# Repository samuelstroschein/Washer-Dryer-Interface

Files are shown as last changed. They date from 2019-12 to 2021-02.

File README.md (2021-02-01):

# A washing machine/dryer status "illuminated sign"

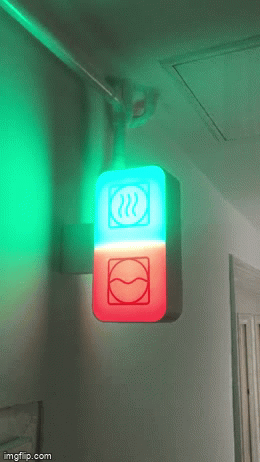
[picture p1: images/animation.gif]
animation


## Summary:

An illuminated sign that indicates whether the dryer and/or washing machine is running, finished or off. An ESP8266 processes information and sends instructions over WiFi to another ESP8266, which is built into the illuminated sign, which light(s) to turn on or off. The "sign ESP8266" controls two separate LED strips which represent either the washing machine or dryer respectively. Since all logic is happening on the client which is not build into the sign, adjusting the programmed logic when your dryer or washer is on or off is easily modifiable to suit your needs. Theoretically, you can just build the sign and display whatever you want or modify the CAD file to make the illuminated sign "wall mountable" (like a clock). 

## Technical Details

### What you need:

1. 2x ESP8266
2. (based on number of appliances)x Photo-resistors and if you have a complicated appliance a motion sensor.
3. 1x LED Strip
4. 3D printer
5. 2x Glass panes optimised for LED's
6. "Spritzspachtel" → Spray filler (to smoothen the 3D print)

### Software

Disclaimer: I started this project with 0.1% of knowledge in programming: The code is bad, like really bad. 
- The first versions did not make use of objects (duplicate code for washer and dryer). After learning about object oriented programming that was implemented (but not from scratch).
- Did not know what HTTP requests or JSON files are. The communication is done via a HTTP Get request which send 4 boolean values (REST safe you know haha).  

**Client:** 

The ESP connected to the vibration sensors and PIR sensor is the client. All logic (appliance running etc.) is happening on the client. This ensures that the logic can easily be easily be modified because of the much easier access to the client ESP than the server ESP. Most appliances have light indicators if it is running or finished. The photo-resistors are placed above these lights. You have to figure out yourself which light does indicate what. The code detects if the light is blinking or continuously on and you can also specify multiple lights for an appliance. For example, my dryer has one led. This led blinks when the dryer is finished and is continuously on when it's running while the washer has two separate lights for on and finished.

The client sends four boolean values to the server which tell the server which lights to turn on like that: *[bool washerRunning(red light), bool washerFinished(green light), bool dryerRunning(red light), bool dryerFinished(green light)].* 

**Server:**

The server receives the instructions which lights to turn on and off by the client. This information is processed and to corresponding LED strips and colors are turned on or off. 

**Generally** the code is easy (and I think understandable). The only pitfall that comes to my mind is the amateurish communication over WiFi.

### Hardware

**Electronic Circuit** for the Server:

Since the server ESP is build into the sign itself, a 5V power supply was needed. Additionally, 12V power supply was also necessary in order to power the LED strips. Therefore, a small electronic circuit had to be developed. Again a disclaimer: I had no experience with electronics. I am sure there are things to improve. The following shows the circuit:

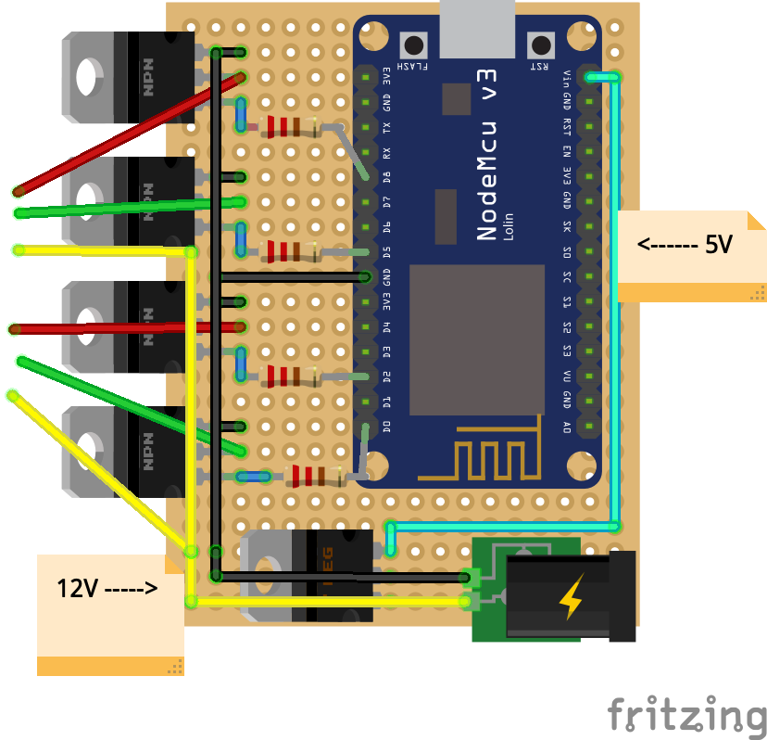
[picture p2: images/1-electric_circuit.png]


The circuit of the server ESP which is connected to the LED strips.

The board is 70x50mm.

The black box on the bottom right is a DC jack where the original LED strips power supply goes into. The original power supply gives out 12V which is represented by the yellow cable. Besides going directly to the LED strips, the 12V also go into a voltage regulator which lowers the voltage to 5V from which the ESP can be powered via the VIN pin (the cyan cable). I used a L78505CV voltage regulator. The four NPN transistors are used to turn on the corresponding colors on the LED strip. I used TIP120 transistors. The input pins from the transistors (most left) are connected to output pins of the ESP. In between each of this connections is 220 ohm resistor. The middle pin is the output for the LED strips. The most right pin is connected to the ground. 

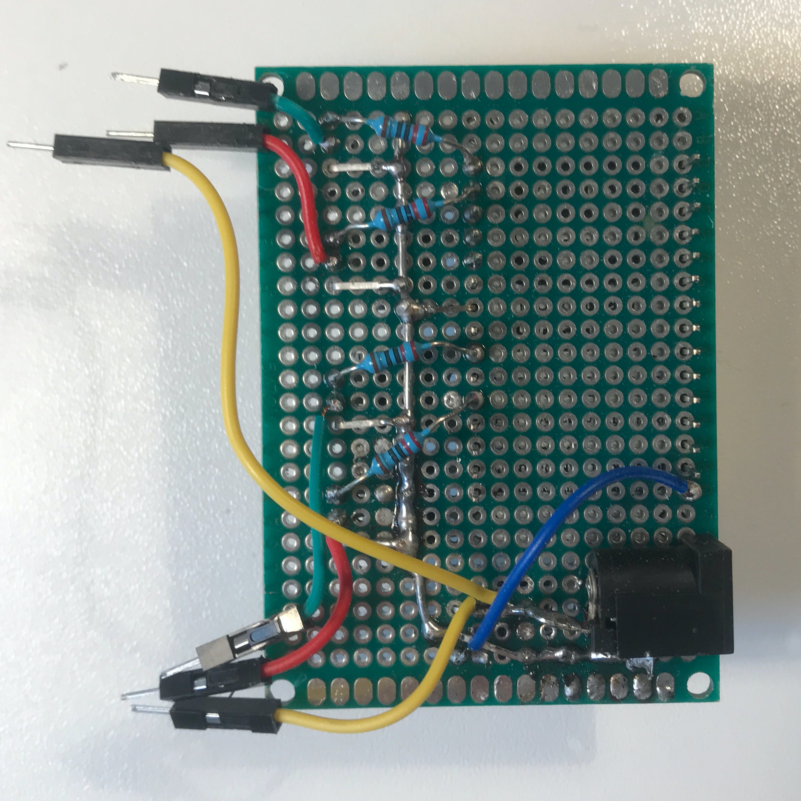
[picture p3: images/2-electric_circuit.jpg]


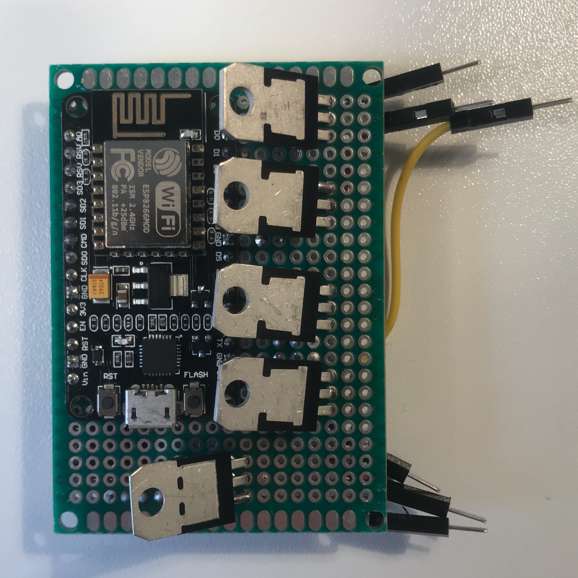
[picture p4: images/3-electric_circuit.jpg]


**3D printed sign**

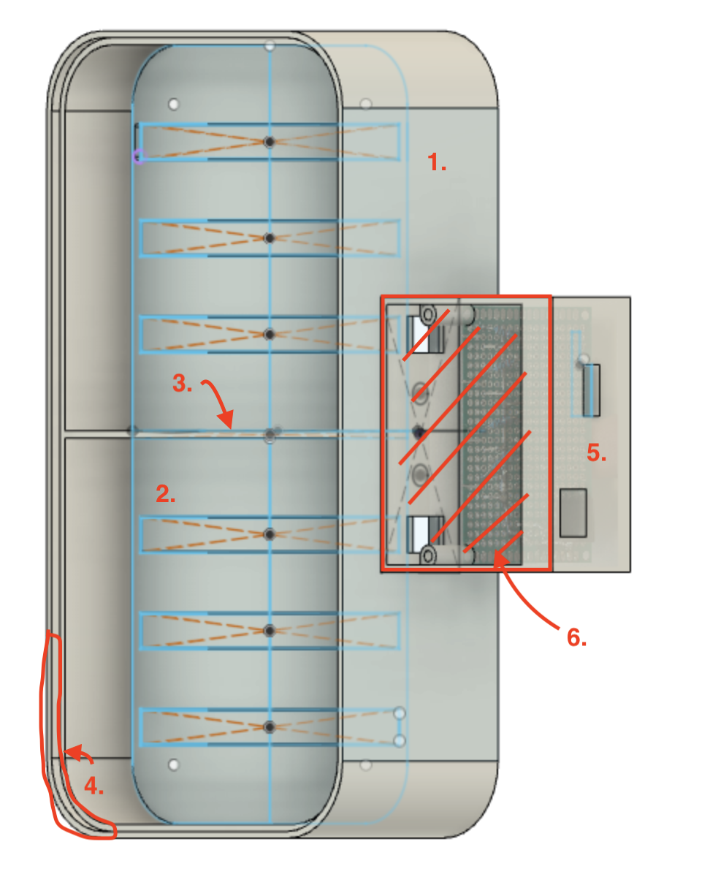
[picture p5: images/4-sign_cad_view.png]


The 3D printed sign consists of 6 (+2 for the glasses) individual parts which are mostly put together by press fit and therefore easy to dismantle again. The dimensions are chosen to be printed by an Ender3 and that the LED strips are diffused by the plexiglass. The hardest part to get is likely the plexiglass. Alternatively, you could try to print a very thin layer with your 3D printer. If you live in Berlin, you can buy the plexiglass from ["Walter Weissig GmbH"](https://www.walterweissig.de/). It's a very old school company manufacturing everything around plexiglass in a typical Kreuzberger backyard since 1918. (These kind of manufacturing facilities are dying out, so if you are in Berlin, go there.)

1. The main case (print without the "glass frame", see point 4).
2. The led plate
3. A divider for the different cells which is glued onto the led plate
4. One "glass frame" which cannot be printed from one side and therefore has to be glued onto the main case. In order to print that part take the main case and only print the "frame" by "moving the case under build plate". This image after the list illustrates this trick.
5. The ESP case
6. A cover for the ESP case
7. (Photo-resistor "case").
8. (Plexiglass + transparent foil with icons printed on them), dimensions are found in stl folder, icons in icons
9. (Plexiglass + transparent foil with icons printed on them), dimensions are found in stl folder, icons in icons

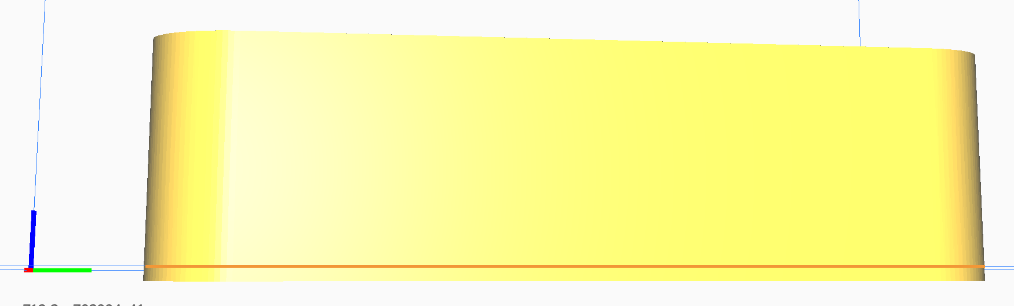
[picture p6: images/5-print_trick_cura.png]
    

    Print trick "under the buildplate". The orange line is the build plate.

## FAQ

**Why did you build this?**

I always forgot my laundry in the washing machine and dryer. The best solution to inform me when the dryer or washing machine is finished is when I walk by the "washing kitchen". (No annoying notifications!).

**What's the motion sensor for?**  
If you have a complicated appliance that does not allow for a heuristic when the appliance is emptied, like my dryer, you can use the motion sensor. If (appliance.isFinished && motionDetected) -> turn appliance.finishedLed off

## Process

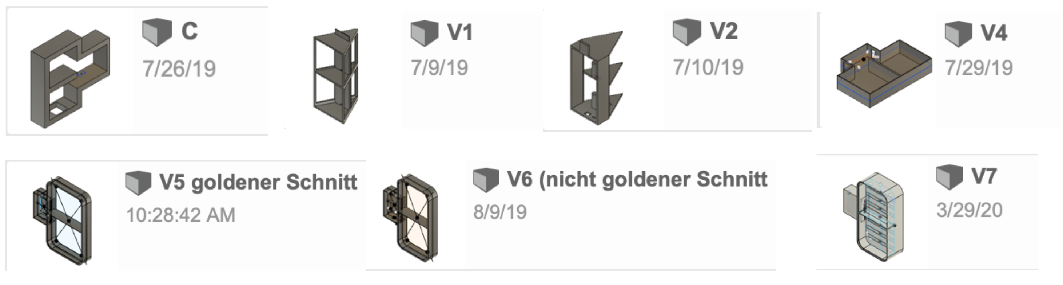
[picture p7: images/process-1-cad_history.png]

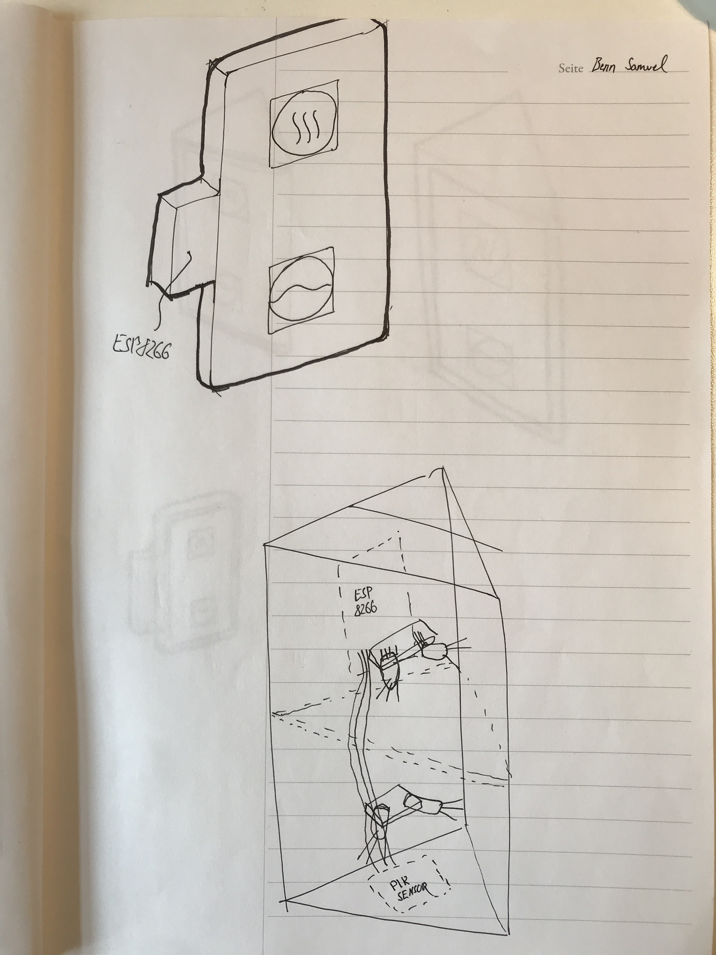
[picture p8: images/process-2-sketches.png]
sketches

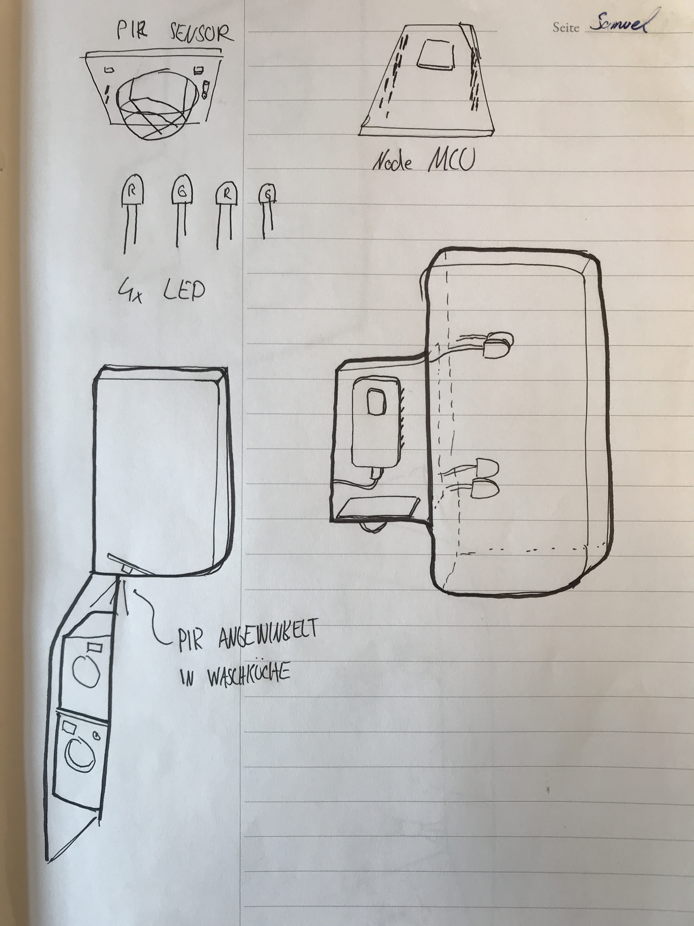
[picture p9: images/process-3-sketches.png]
sketches

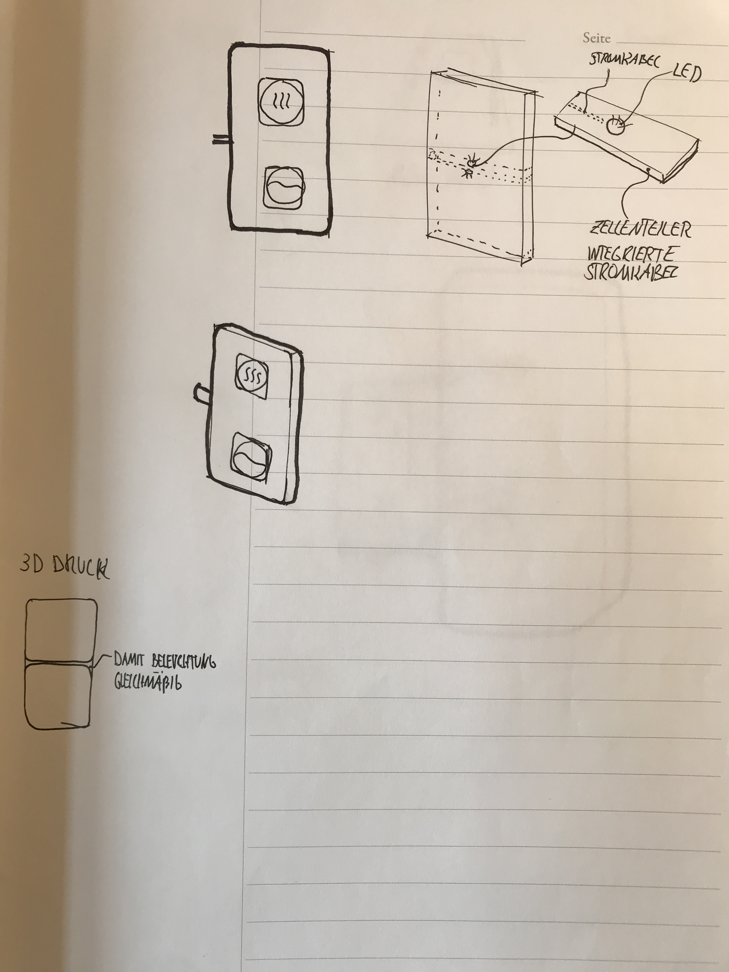
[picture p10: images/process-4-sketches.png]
sketches

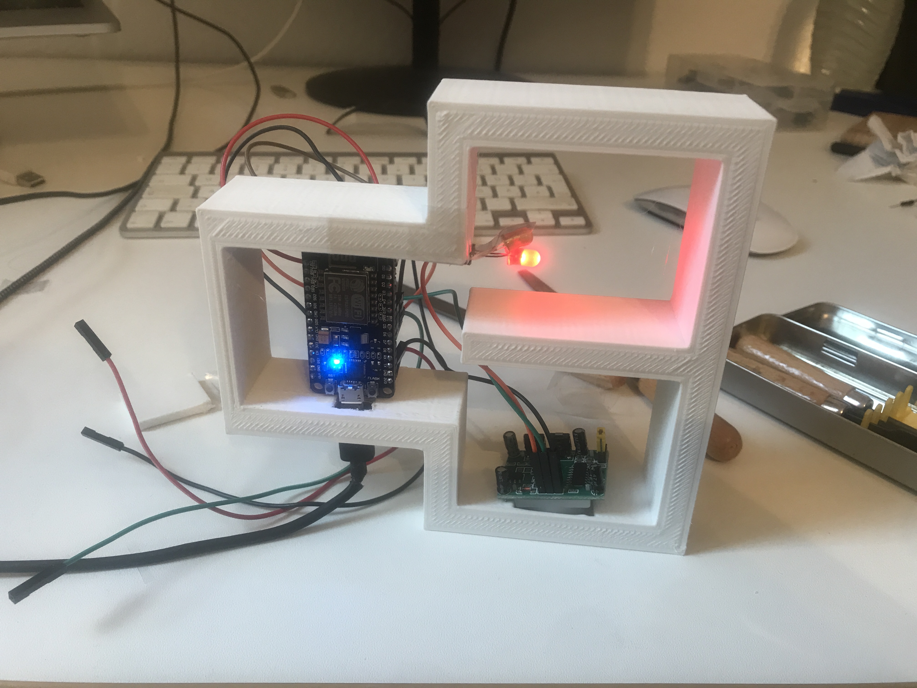
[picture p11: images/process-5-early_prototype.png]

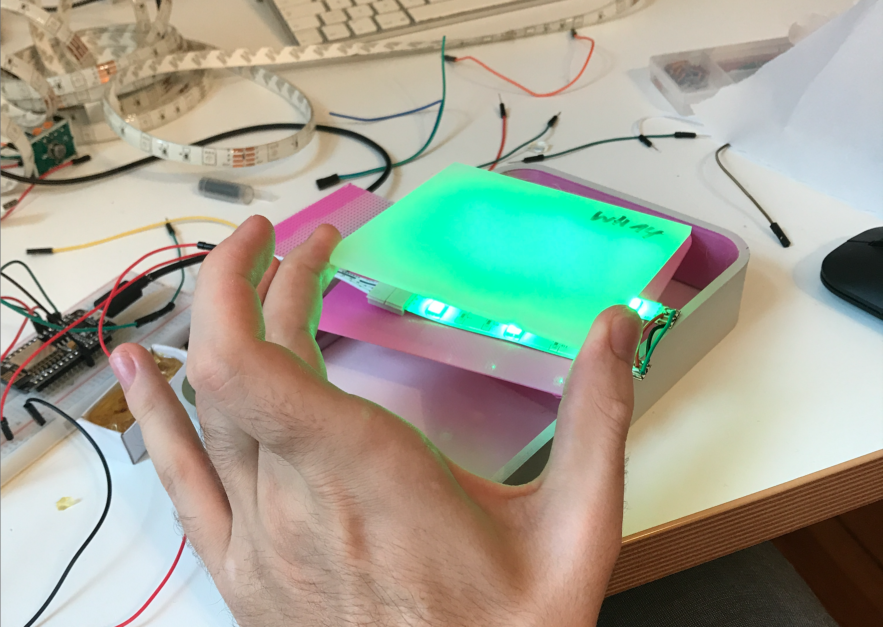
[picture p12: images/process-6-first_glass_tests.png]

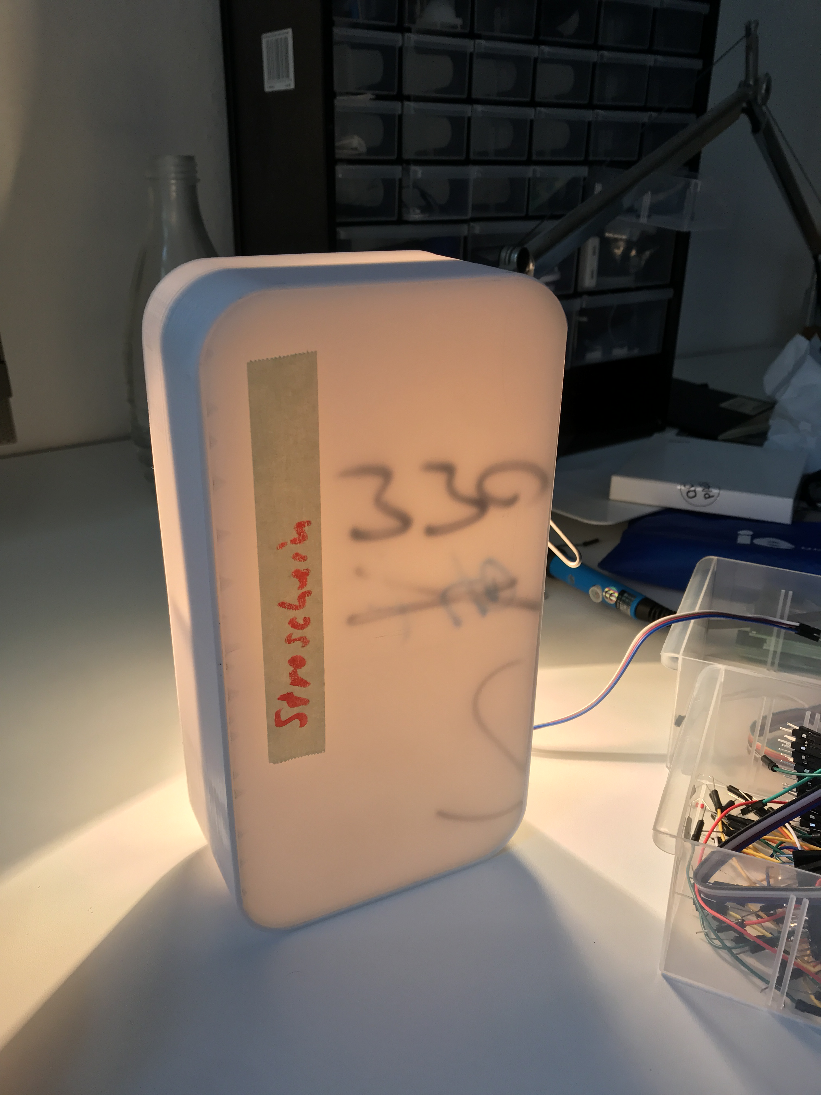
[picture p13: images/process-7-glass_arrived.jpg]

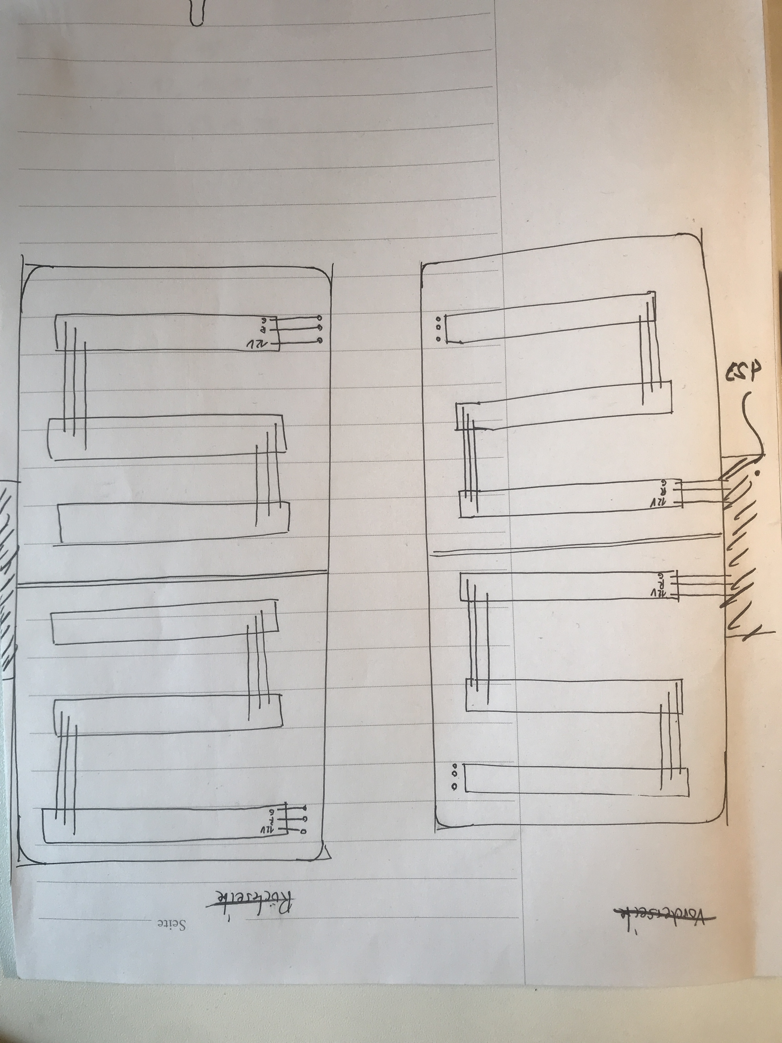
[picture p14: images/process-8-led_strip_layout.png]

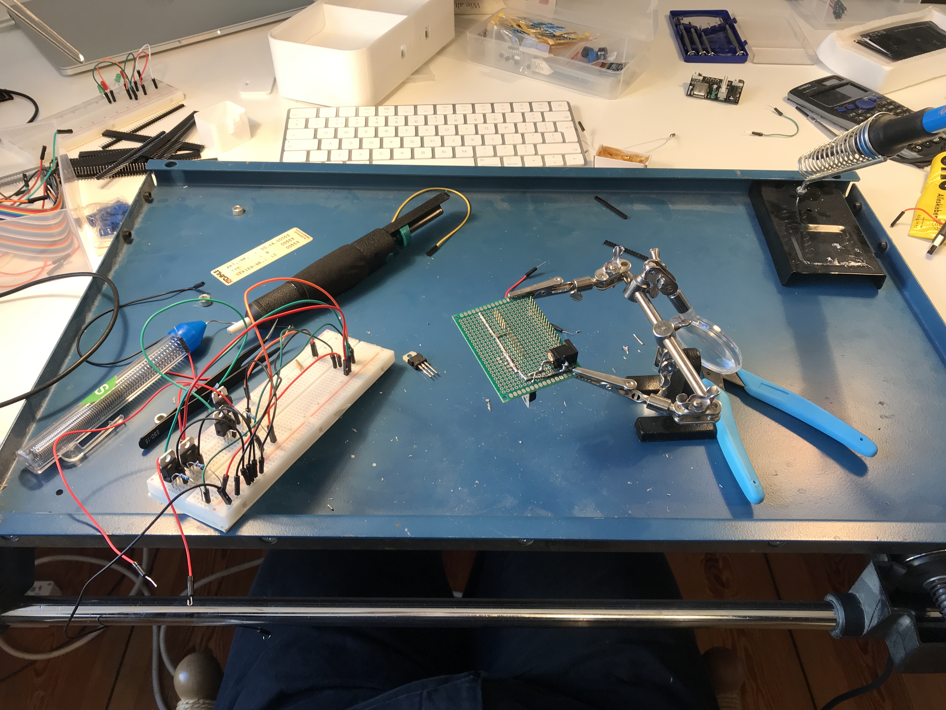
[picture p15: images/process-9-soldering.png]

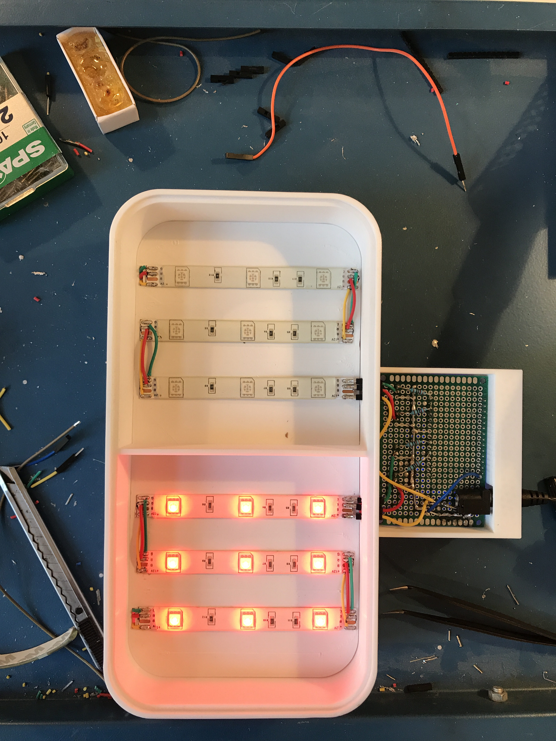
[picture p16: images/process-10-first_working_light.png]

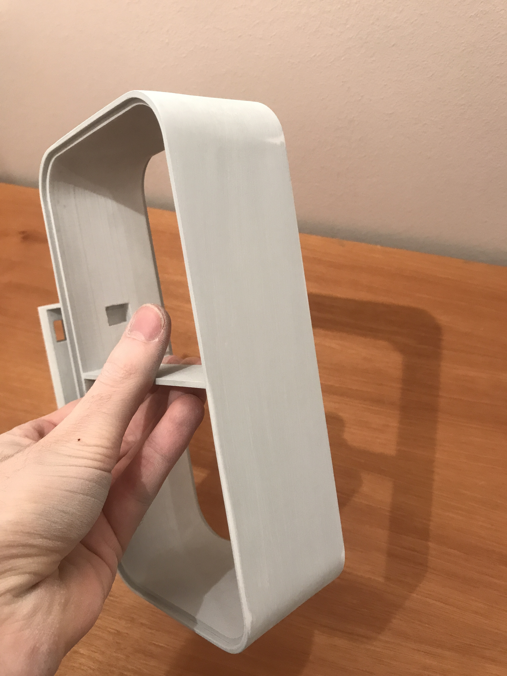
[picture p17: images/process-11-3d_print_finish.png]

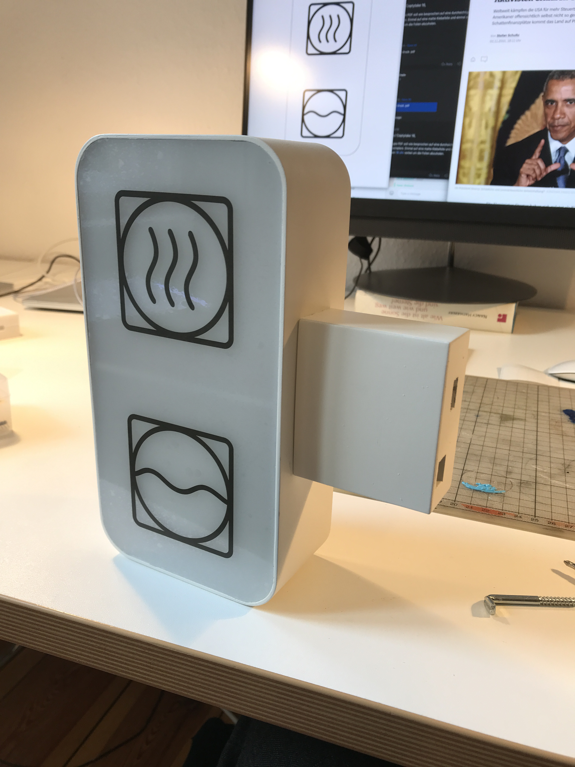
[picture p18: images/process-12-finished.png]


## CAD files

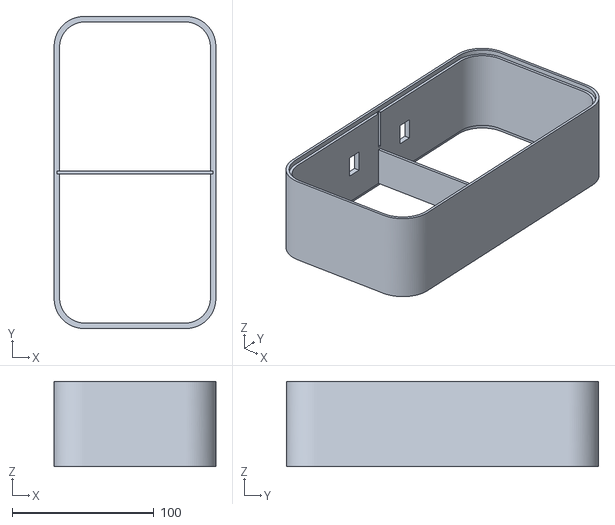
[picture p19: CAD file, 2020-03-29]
3D_print/STL files/1. main_case.stl
114.0 x 220.0 x 60.0

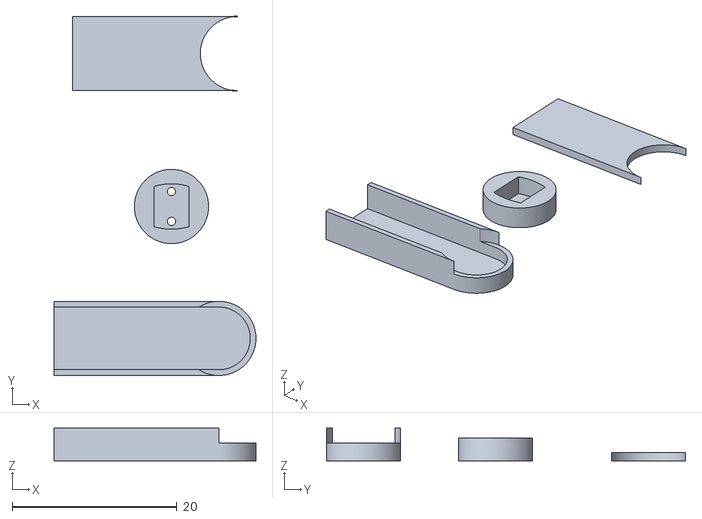
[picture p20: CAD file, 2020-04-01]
3D_print/STL files/7. photo-resistor case.stl
24.5 x 43.5 x 4.00

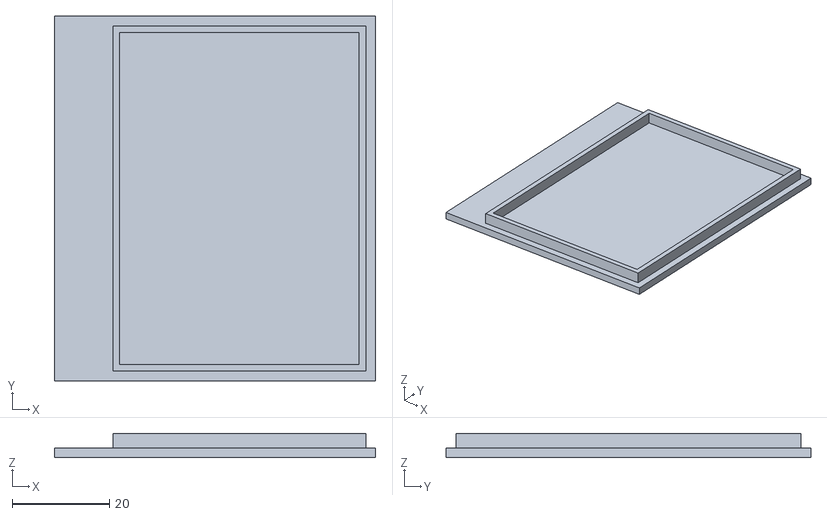
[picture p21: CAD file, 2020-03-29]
3D_print/STL files/6. esp_case_cover.stl
66.0 x 75.0 x 5.00

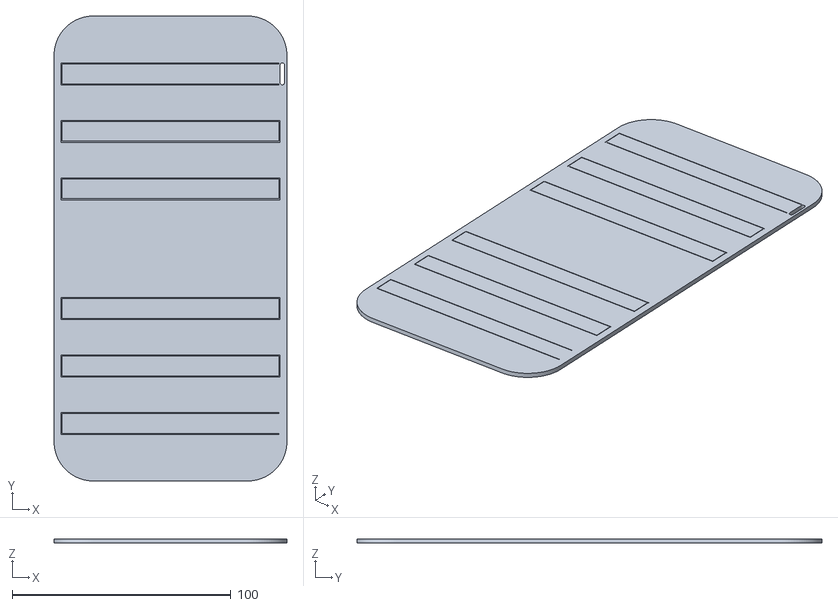
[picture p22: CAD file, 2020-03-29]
3D_print/STL files/2. led_plate.stl
106.4 x 212.4 x 2.00

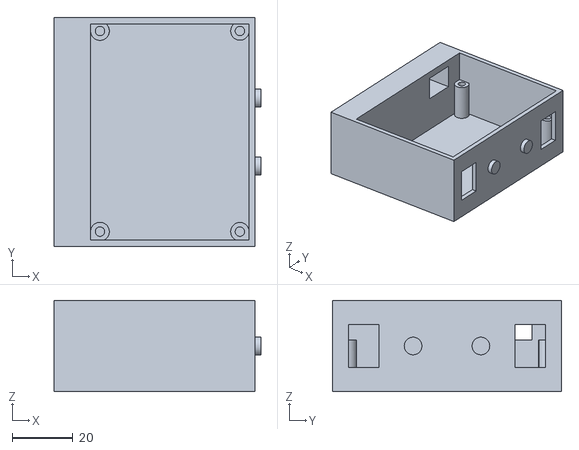
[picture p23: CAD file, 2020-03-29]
3D_print/STL files/5. esp_case.stl
67.9 x 75.0 x 30.0

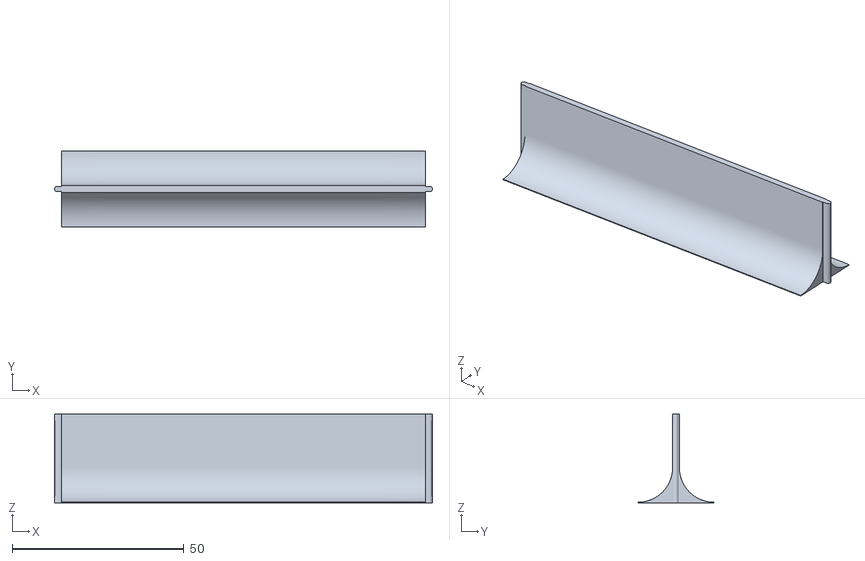
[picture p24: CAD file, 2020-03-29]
3D_print/STL files/3. led_divider.stl
110.0 x 22.0 x 25.8

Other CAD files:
CAD_source_files/Sign.f3d
CAD_source_files/photo-resistor case.f3d

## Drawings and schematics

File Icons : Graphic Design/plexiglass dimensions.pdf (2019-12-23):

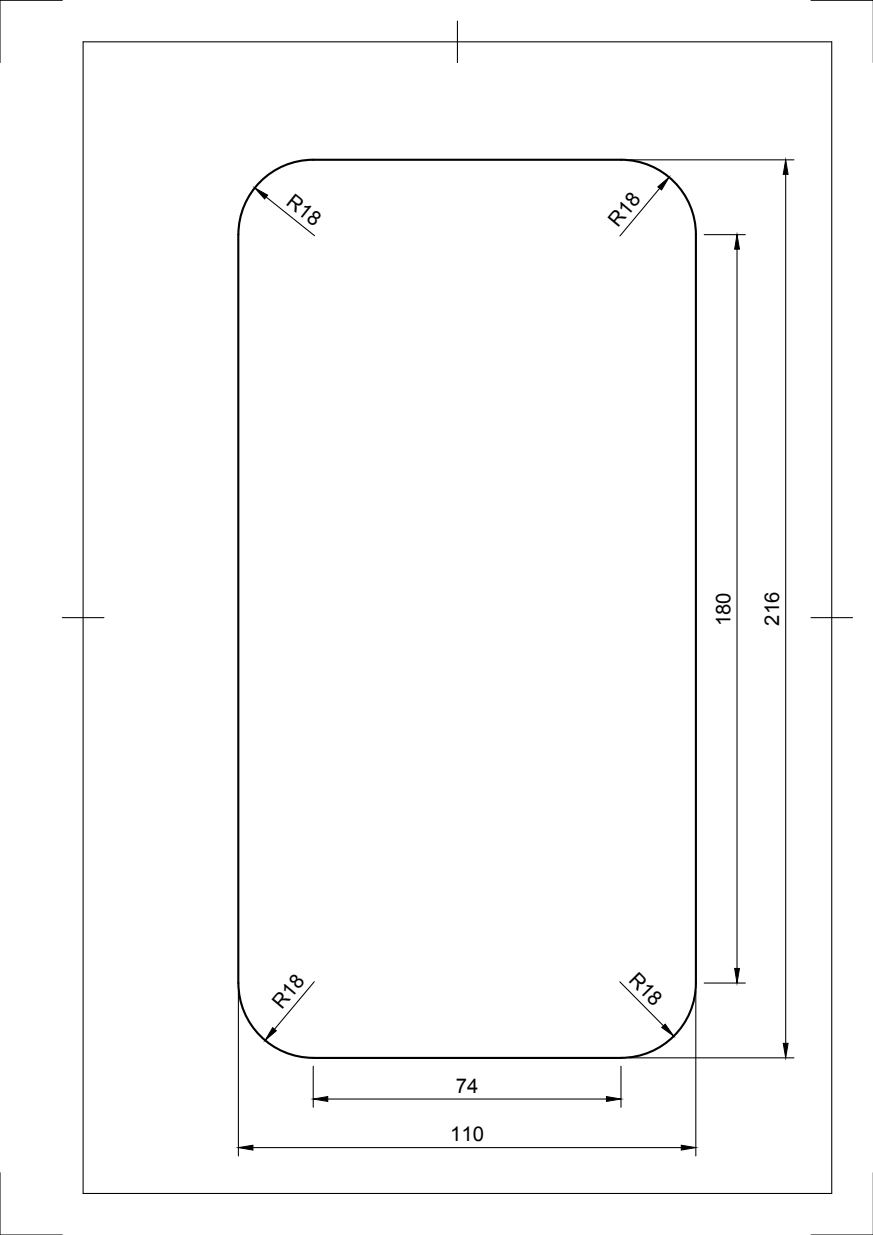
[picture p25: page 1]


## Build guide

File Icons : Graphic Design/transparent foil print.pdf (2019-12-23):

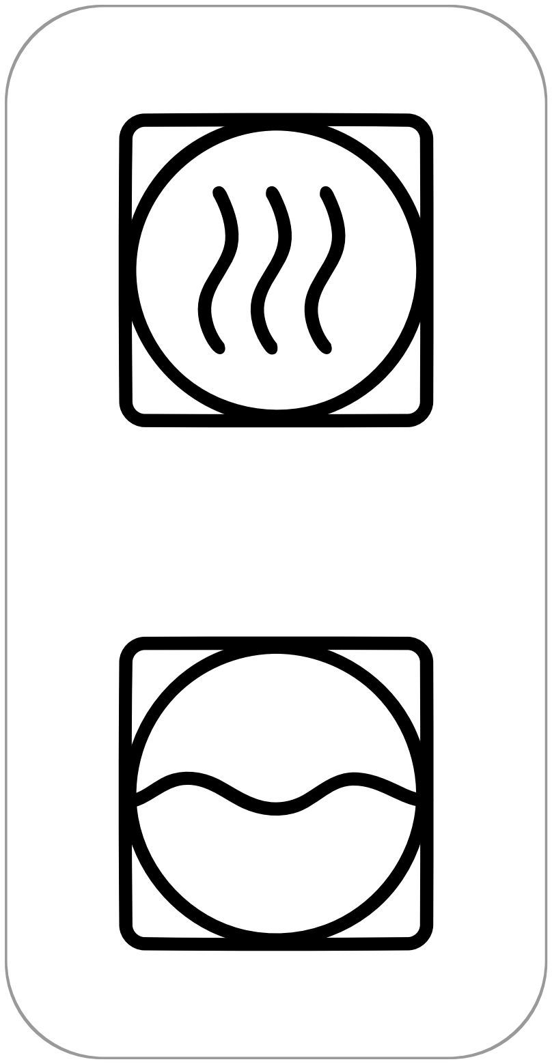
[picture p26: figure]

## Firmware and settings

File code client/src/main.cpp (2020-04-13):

# include <Arduino.h>
# include <ESP8266WiFi.h>
# include <appliance.h>
# include <pirSensor.h>

// Wifi server credentials
const char *ssid = "WDI_Server2";
const char *password = "macbook1";

// Pins of sensor 
const int washerOnSensorPin = 14;
const int washerFinishedSensorPin = 4;
const int dryerCombinedSensorPin = 5; 
const int pirSensorPin = 0;



// Appliances
Appliance washer(washerOnSensorPin, washerFinishedSensorPin);
Appliance dryer(dryerCombinedSensorPin);

// Motion (PIR) Sensor
PirSensor pir(pirSensorPin);

// query which contains the BOOLEAN values which light should be on
String dataString = "";


// --------------- definition of methods(functions) ------------------------


void appendDataString(Appliance appliance){
  if (appliance.isRunning()){
    dataString += "1";  // appliance running
    dataString += "0";  // appliance not finished
  }
  else if (appliance.isFinished()){
    dataString += "0";  // appliance not running
    dataString += "1";  // appliance finished
  }
  else {
    dataString += "0";
    dataString += "0";
  }
}

void connectedSignIndicator(){
  WiFiClient client;
  const char * host = "192.168.4.1";
  const int httpPort = 80;
  String url = "/data/?sensor_reading=1111";
  if (!client.connect(host, httpPort)) {
    Serial.println("connection failed");
  }
  client.print(String("GET ") + url + " HTTP/1.1\r\n" +
              "Host: " + host + "\r\n" +
              "Connection: close\r\n\r\n");
}


// ---------------------- START OF PROGRAM -----------------------

void setup() {
  Serial.begin(9600);
  delay(10);

  // We start by connecting to a WiFi network

  Serial.println();
  Serial.println();
  Serial.print("Connecting to ");
  Serial.println(ssid);
  Serial.println("");
  Serial.println("WiFi connected");
  Serial.println("IP address: ");
  Serial.println(WiFi.localIP());

  WiFi.begin(ssid, password);

  while (WiFi.status() != WL_CONNECTED) {
      delay(500);
      Serial.print(".");
  }
  // once client connects to server (sign) all lights turn on for 1 sec.
  connectedSignIndicator();
  delay(1000);
}


void loop() {
  // Use WiFiClient class to create TCP connections
  WiFiClient client;
  const char * host = "192.168.4.1";
  const int httpPort = 80;

  client.setTimeout(1000);
  if (!client.connect(host, httpPort)) {
    Serial.println("connection failed");
  }


  // This is the order in which LED instructions are send. 
  // [WasherIsRunning, WasherIsFinished, DryerIsRunning, DryerIsFinished]
  dataString = "";

  washer.turnedOnSensor.measure();
  washer.finishedSensor.measure();
  dryer.combinedSensor.measure();
  pir.measure();

  // appends information about washer first e.g "01" (washer not running, washer finished)
  // then information about dryer e.g. "00" (dryer not running, dryer not finsihed)
  appendDataString(washer);
  appendDataString(dryer);
  
  // create a URI for the request. Something like /data/?sensor_reading=
  //                               [WasherIsRunning, WasherIsFinished, DryerIsRunning, DryerIsFinished]
  String url = "/data/";
  url += "?sensor_reading=";
  url += dataString;

  // send data string to server
  client.print(String("GET ") + url + " HTTP/1.1\r\n" +
                "Host: " + host + "\r\n" +
                "Connection: close\r\n\r\n");

  // To turn off the finished status
  // double if statement because both can be finished at the same time
  if (pir.detectsPerson()){
    if (washer.isFinished()){
      washer.wasEmptied();
    }
    if (dryer.isFinished()){
      dryer.wasEmptied();
      //! wasRunning bug bypass
      dryer.wasRunning = false;
    }
  }

  //! statement implemented to bypass bug in wasRunnning variable in class appliance
  if (dryer.isRunning()){
    dryer.wasRunning = true;
  }


  // Debug print statements (how does the debugger work for external hardware????)

    // Serial.println("Washer:");
    // Serial.println(washer.turnedOnSensor.lightOn());
    // Serial.println(washer.finishedSensor.lightOn());
    // Serial.println(washer.isRunning());
    // Serial.println(washer.isFinished());
    // Serial.println("Dryer");
    // Serial.println(dryer.combinedSensor.lightOn());
    // Serial.println(dryer.combinedSensor.lightBlinking());
    // Serial.println(dryer.isRunning());
    // Serial.println(dryer.isFinished());
    // Serial.println(dataString);
    // Serial.println("");

    Serial.println("Washer:");
    Serial.println(washer.turnedOnSensor.read());
    Serial.println(washer.finishedSensor.read());
    Serial.println("Dryer");
    Serial.println(dryer.combinedSensor.read());
    Serial.println(dryer.combinedSensor.count());
    Serial.println("Pir:");
    Serial.println(pir.motionCounter);
    // Serial.println(pir.detectsPerson());
    Serial.println(dataString);
    Serial.println(dryer.wasRunning);
    Serial.println(dryer.combinedSensor.read());
    Serial.println("");
    
  delay(500);
}

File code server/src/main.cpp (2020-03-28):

# include <Arduino.h>
# include <ESP8266WiFi.h>
# include <ESP8266WebServer.h>
# include <serverAppliance.h>


// Server
const char *ssid = "WDI_Server2";
const char *password = "macbook1";
ESP8266WebServer server(80);


// LED PINS

const int dryerFinishedLedPin = 16;
const int dryerRunningLedPin = 5;


const int washerFinishedLedPin = 12;
const int washerRunningLedPin = 15;   // led connected to GPIO2 (D4)


// Appliances
Appliance dryer(dryerRunningLedPin, dryerFinishedLedPin);
Appliance washer(washerRunningLedPin, washerFinishedLedPin);


void handleSentVar() {
  if (server.hasArg("sensor_reading")) { 
    // dataString = ["bool washerRunning, bool washerFinished, 
    //                bool dryerRunning, bool dryerFinished"]
    String dataString = server.arg("sensor_reading");

    washer.clientInput(dataString.charAt(0), dataString.charAt(1));
    dryer.clientInput(dataString.charAt(2), dataString.charAt(3));

    Serial.println(dataString.charAt(0));
    Serial.println(dataString);

    server.send(200, "text/html", "Data received");
  }
}

void setup() {

  Serial.begin(9600); //Default Baudrate

  delay(1000);

  WiFi.softAP(ssid, password);
  IPAddress myIP = WiFi.softAPIP();

  server.on("/data/", HTTP_GET, handleSentVar); // when the server receives a request with /data/ in the string then run the handleSentVar function
  server.begin();
}

void loop() {
  server.handleClient();
  washer.processLights();
  dryer.processLights();

}

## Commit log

2019-12-23 created project for ESP32
2019-12-23 ldr and led working without objects
2019-12-23 led object created and working
2019-12-23 implemented ldr.ledIsOn()
2019-12-24 second led test
2019-12-24 Appliance self Led implemented
2019-12-26 led strip | added analogWrite
2019-12-27 working green red led with Plot
2019-12-29 changed client to esp32
2019-12-31 end of december work
    Problems:
    -Wifi connection drops on continious basis.
    [main.cpp]
2020-03-21 deleted esp32 client
2020-03-25 corrected to else if
    [main.cpp]
2020-03-28 changed pinout
    [WDI Fritzing.fzz]
2020-03-29 removed old code
    [WDI Fritzing.fzz]
2020-03-29 added stl files
    [1. main_case.stl, 2. led_plate.stl, 3. led_divider.stl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]
2020-03-30 added more stl files
    [caja_v1.stl, drop_ceiling_mount_and_box_for_arduino_pirm_sensor.skp.stl, pinza_pared.stl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]
2020-03-30 removed old esp32 code
2020-04-01 translated to english
    [7. photo-resistor case.stl, Sign.f3d, caja_v1.stl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]
2020-04-06 implemented timer heuristic for combinesSensor
2020-04-06 re-implemented pir sensor
2020-04-06 removed timer heuristic
2020-04-06 implemented wasRunning bug work around
    [ldr.h, main.cpp]
2020-04-06 Update README.md
    added passage about motion (pir) sensor
